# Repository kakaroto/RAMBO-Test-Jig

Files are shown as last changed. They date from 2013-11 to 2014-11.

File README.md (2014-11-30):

# RAMBO Test Jig
These files are the scad sources of a Test Jig used for testing RAMBo boards. It is still incomplete but should be close to final version.

This Test Jig design is based on the Test Jig designed by sjkelly from Ultimachine (https://github.com/ultimachine/Test-Jig) but is much simpler to build. 

You will need to have Magpie installed or copied to this directory for the scad to generate correctly.

# Instructions
First, you should print the calibration-test file which will help you decide which size of holes to use for your printed boards. I have found that my printer was not accurate enough (or not well calibrated) so the hole sizes were not very accurate, but a small enough size is good enough to keepboard integrity (we don't want the middle lines to break in the 3x2 header for example) and big enough to appear correctly and guide a drill into them.

I have drilled every hole in my boards and found correct drill sizes that allow the pogo pins to fit nicely.
Another important file is configuration.scad, where you can specify the size of the holes, the radius and width/height of M3 bolt and nut, the size of the clamps, etc...

Once it's done, you should print the foot, bottom_spacer, board_spacer, RAMBo bottom plate, middle plate and top plate with clamps, the simple encoder and the motor and opto mounts.

Here is the list of files and what they are used for :

* calibration-test.scad : Calibration print to test hole sizes and printer accuracy
* configuration.scad : Configuration of holes sizes and board vias and settings to use for other parts
* common.scad : Main include, has some helper functions used by multiple modules
* RAMBo.scad : RAMBo board definition. Do not print
* foot.scad : The foot of the wooden plate on which to build the jig
* controller_spacer.scad : Spacer between the wooden plate and the controller
* bottom_spacer.scad : Spacer between the controller and the bottom board (print twice per rod)
* board_spacer.scad : Spacer between the bottom board and the middle one
* RAMBo_bottom_plate.scad : Bottom plate on which to insert pogo pins
* RAMBo_middle_plate.scad : Middle plate on which the top of the pogo pins goes
* RAMBo_top_plate.scad : Top plate used to push down on the RAMBo
* clamp.scad : Clamp used on the top plate for clamping into the middle plate
* motor_mount.scad : Mount to hold the motors to the wooden plaque
* opto_mount.scad : Mount to hold the opto endstop to the motor
* simple_encoder.scad : The encoder flag for the motors

All files have had their STL generated and saved in the stl directory.

# Assembly
Use a RAMBo as controller, remove all resistors/capacitors from the thermistor area.

The assembly is simple, first screw the feet to the wooden plate, drill holes in it for all the elements that it will hold, insert M3 rods into holes and use controller spacer to separate the wooden plate with the controller board, then add the controller, two bottom spacers per rod, the bottom board, the board spacer, then middle board. Insert pogo pins, use epoxy glue on the bottom board if you want to, and tighten everything.

Install clamps to the top board, and test the system. 

Hold the motors with the motor_mount, and attach the opto endstop to the opto mount and attach it to the motor. insert the encoder in the motor, and screw everything to the wooden plate.

Connect all the wires from the pogo pins to the controller and extra resistors.

Use 4.7KOhm and 47KOhm resistors as voltage divider for your supply rail tests, and a 100KOhm resistor for the thermistor tests.

# Pin mapping
Endstops :
```
 Xmin to EXT2-10
 Ymin to EXT2-12 
 Zmin to EXT2-14 
 Xmax to EXT2-16 
 Ymax to EXT2-18  
 Zmax to EXT2-20 
 ```
Mosfets :

```
 Heat0 to MX3-4
 Fan0 to MX3-5
 Heat1 to MX2-4
 Fan1 to MX2-5
 Heat-Bed to MX1-5
 Fan2 to MX1-4
 ```
VRefs:

```
 XRef to Analog-Ext-8
 YRef to Analog-EXT-6
 ZRef to Analog-EXT-5
 E0-Ref to Analog-EXT-4
 E1-Ref to Analog-EXT-3
 ```
Supply voltage:

```
 Extruder rail (Heat0+) to T3
 Bed rail (Heat-Bed+) to T2
 5V rail (VCC middle pin of power selector jumper) to T0```
For the supply voltage, we need a 47KOhm resistor between VCC and Tx and a 4.7KOhm resistor between Tx and the ground (R1, R2 according to Ohm's law to get a divider of voltage of 0.91)

Thermistor connectors connected to a 100KOhm resistor

Motors connected to normal motors

Opto-endstops for controller :

```
 X opto endstop to EXT2-9
 Y opto endstop to EXT2-11
 Z opto endstop to  EXT-15
 E0 opto endstop to EXT-17
 E1 opto endstop to EXT-19
```

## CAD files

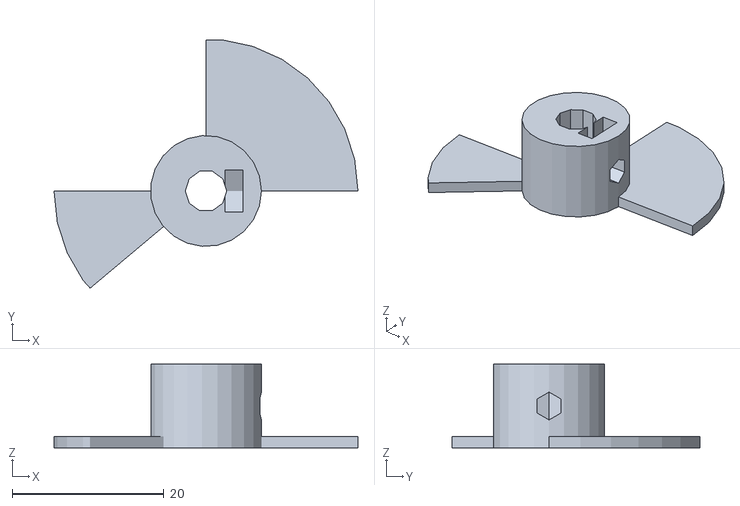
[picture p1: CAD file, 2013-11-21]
stl/RAMBo_1.1/encoder_flag.stl
40.0 x 32.7 x 11.0

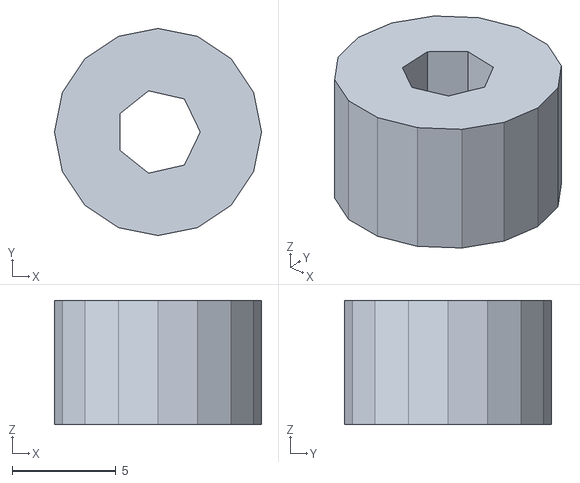
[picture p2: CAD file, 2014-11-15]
stl/RAMBo_1.3/controller_spacer.stl
10.0 x 10.0 x 6.00

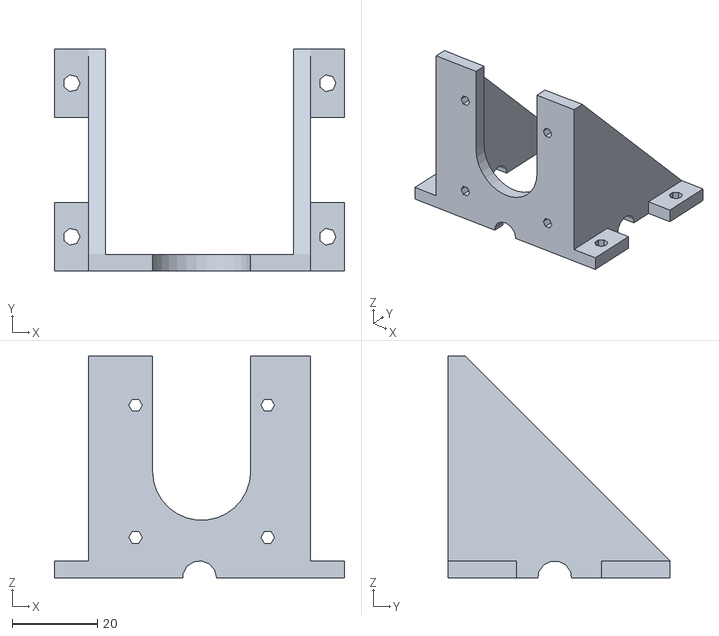
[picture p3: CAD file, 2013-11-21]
stl/RAMBo_1.1/motor_mount.stl
68.0 x 52.0 x 52.0

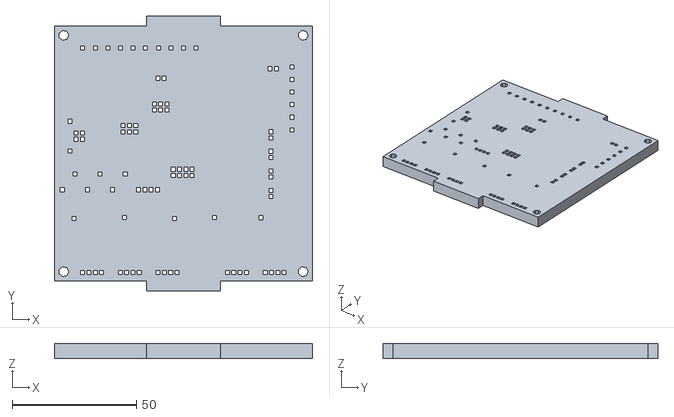
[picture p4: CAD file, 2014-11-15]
stl/RAMBo_1.3/RAMBo_middle_plate.stl
104.1 x 110.9 x 6.00

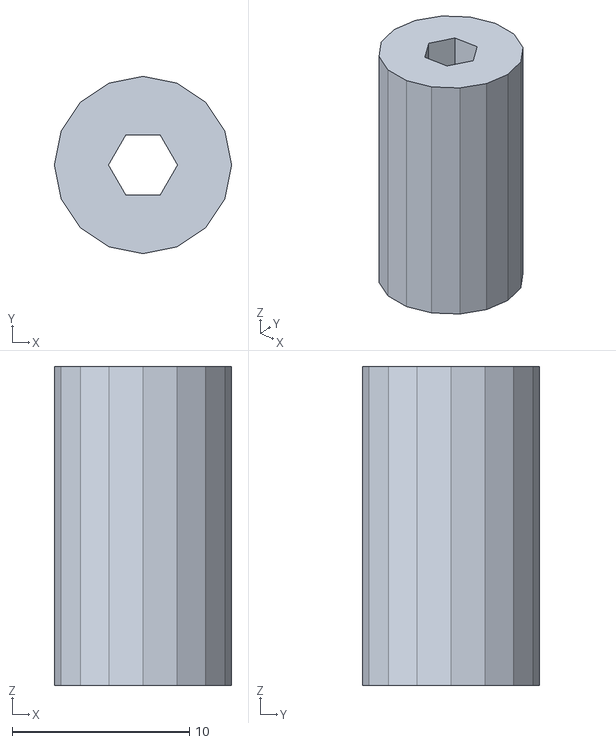
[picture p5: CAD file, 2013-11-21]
stl/RAMBo_1.1/board_spacer.stl
10.0 x 10.0 x 18.0

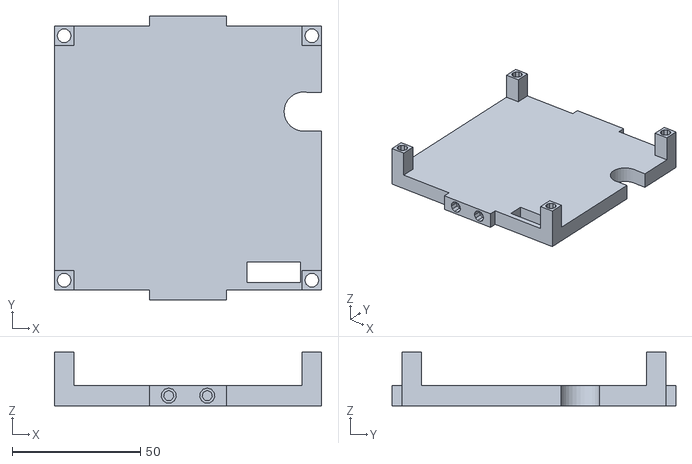
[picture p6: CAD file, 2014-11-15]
stl/RAMBo_1.3/RAMBo_top_plate.stl
104.1 x 110.7 x 21.0

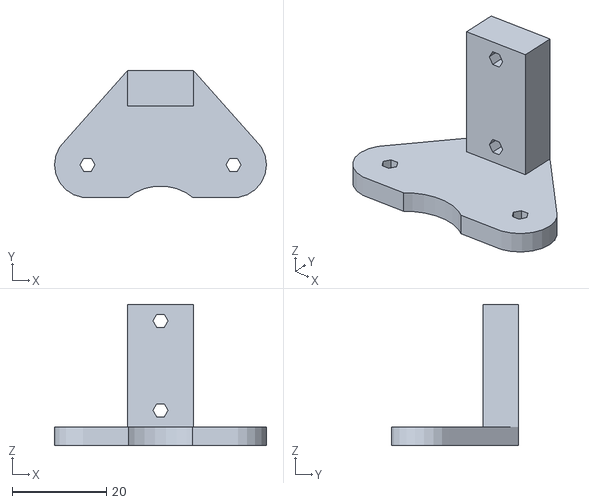
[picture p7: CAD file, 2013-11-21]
stl/RAMBo_1.1/opto_mount.stl
45.0 x 26.9 x 30.0

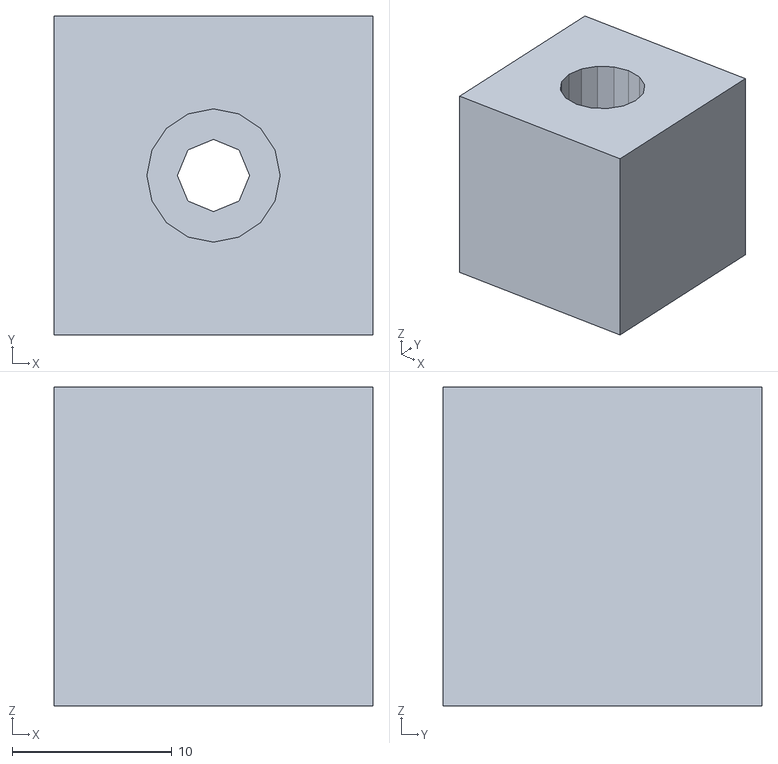
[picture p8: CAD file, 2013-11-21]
stl/RAMBo_1.1/foot.stl
20.0 x 20.0 x 20.0

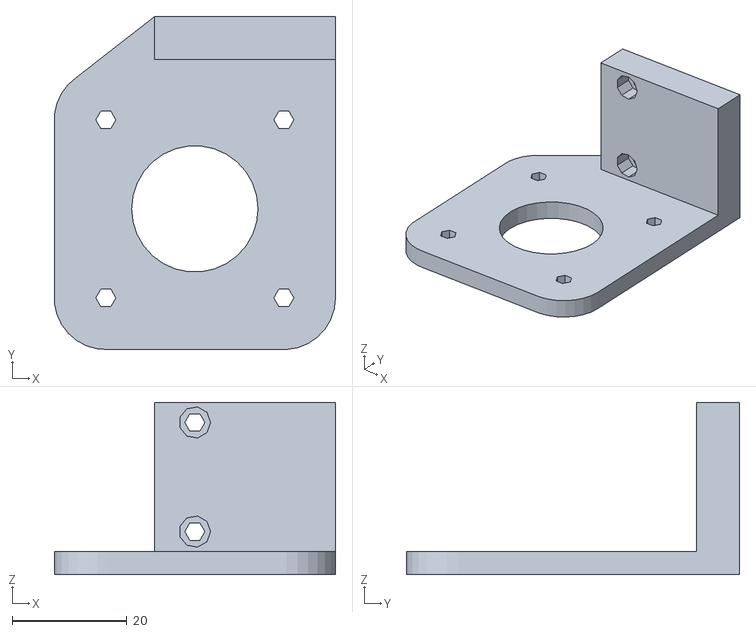
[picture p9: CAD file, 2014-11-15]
stl/RAMBo_1.3/opto_mount.stl
48.9 x 58.0 x 30.0

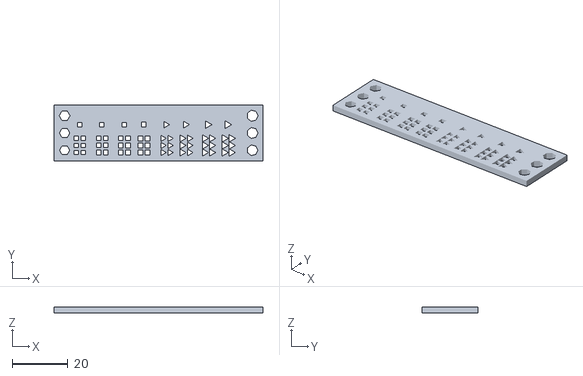
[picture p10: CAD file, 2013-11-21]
stl/RAMBo_1.1/calibration-test.stl
75.0 x 20.0 x 2.00

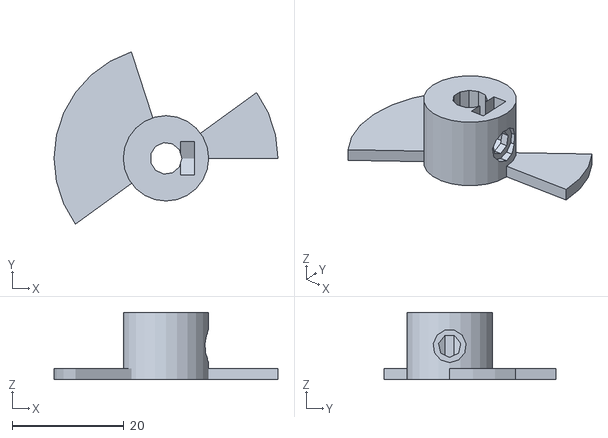
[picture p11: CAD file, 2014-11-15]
stl/RAMBo_1.3/simple_encoder.stl
40.0 x 30.8 x 12.0

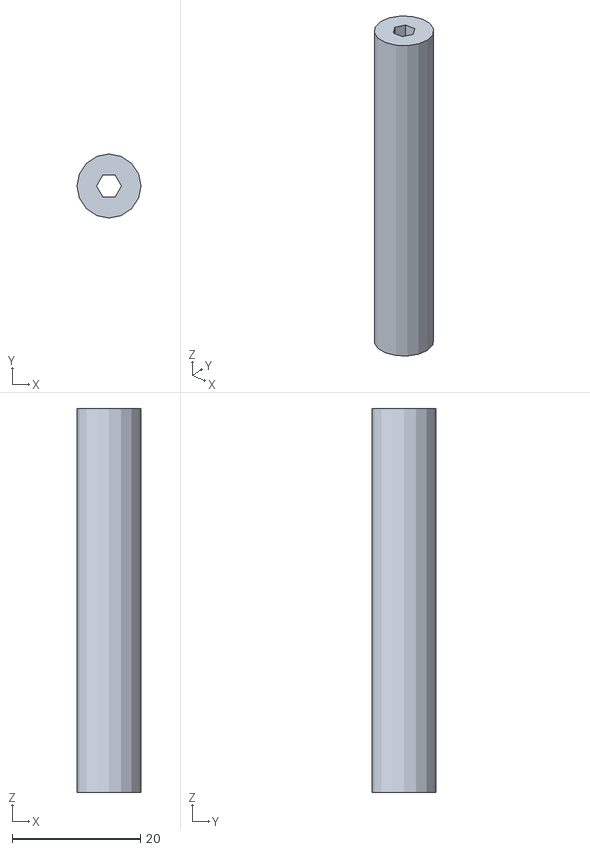
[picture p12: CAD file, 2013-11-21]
stl/RAMBo_1.1/bottom_spacer.stl
10.0 x 10.0 x 60.0

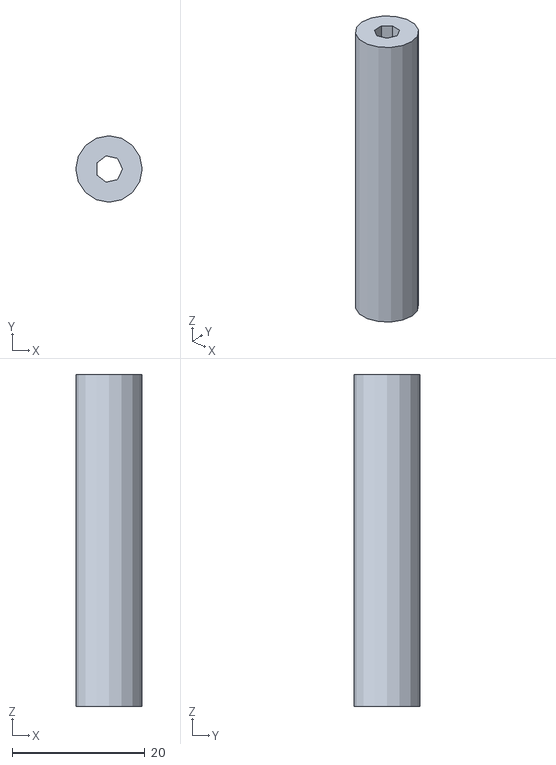
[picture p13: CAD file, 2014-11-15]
stl/RAMBo_1.3/bottom_spacer.stl
10.0 x 10.0 x 50.0

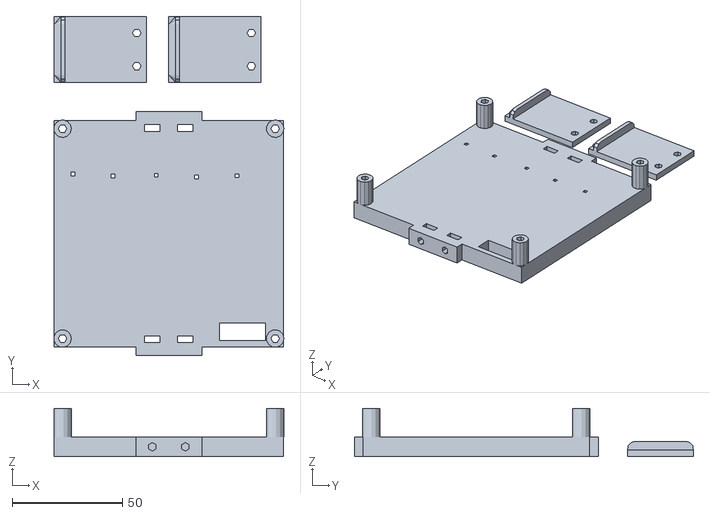
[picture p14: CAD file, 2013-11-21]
stl/RAMBo_1.1/RAMBo_top_plate_with_clamp.stl
104.4 x 153.9 x 22.0

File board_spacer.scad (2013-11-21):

include <common.scad>;

spacer(RECEPTACLE_SPACER_HEIGHT);

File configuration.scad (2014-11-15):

/* Screw holes */
M3_RADIUS=1.75;
M3_HEAD_RADIUS=2.75;
M3_HEATSET_RADIUS=2.75;
M3_HEATSET_LENGTH=4;
M3_LENGTH=13;
M3_NUT_WIDTH=6;
M3_NUT_DEPTH=2.5;
MOUNT_SCREW_RADIUS=2;

/* Spacer sizes */
CONTROLLER_SPACER_HEIGHT=6;
BOTTOM_SPACER_HEIGHT=50;
RECEPTACLE_SPACER_HEIGHT=18;
TOP_SPACER_HEIGHT=13;

/* Clamp settings */
CLAMP_HOOK_WIDTH=4;
CLAMP_HOOK_HEIGHT=5;
CLAMP_HOOK_BORDER_HEIGHT=2;
CLAMP_THICKNESS=3;
CLAMP_WIDTH=30;
CLAMP_HEIGHT=TOP_SPACER_HEIGHT + 22;
CLAMP_USE_HEATSET_INSERTS=1;

/* Foot settings */
FOOT_WIDTH=20;
FOOT_HEIGHT=20;
FOOT_INSET_HEIGHT=10;

/* Motor settings */
MOTOR_MOUNT_THICKNESS=4;
MOTOR_HOLE_DISTANCE=31;
MOTOR_RADIUS=11;
MOTOR_MOUNT_USE_HEATSET_INSERTS=1;

/* opto mount settings */
OPTO_MOUNT_BASE_THICKNESS=4;
OPTO_MOUNT_BASE_HEIGHT=27;
OPTO_MOUNT_RADIUS=9;
OPTO_MOUNT_THICKNESS=7.5;
OPTO_MOUNT_WIDTH=14;
OPTO_MOUNT_HEIGHT=30;
OPTO_MOUNT_USE_HEATSET_INSERTS=1;

/* Default RAMBo settings */
RAMBO_TYPE="1.3";
CORNER_HOLES=1;
MOTOR_X=1;
MOTOR_Y=1;
MOTOR_Z1=1;
MOTOR_Z2=0;
MOTOR_E0=1;
MOTOR_E1=1;
VIN=1;
MOSFET_HEAT0=1;
MOSFET_FAN0=1;
MOSFET_HEAT1=1;
MOSFET_FAN1=1;
MOSFET_HEAT_BED=1;
MOSFET_FAN2=1;
THERMISTOR0=1;
THERMISTOR1=1;
THERMISTOR2=1;
THERMISTOR3=1;
ENDSTOP_POWER=0;
ENDSTOP_XMIN=1;
ENDSTOP_XMAX=1;
ENDSTOP_YMIN=1;
ENDSTOP_YMAX=1;
ENDSTOP_ZMIN=1;
ENDSTOP_ZMAX=1;
ICSP_M32U2=1;
ICSP_M2560=1;
I2C=1;
SERIAL=0;
SPI=1;
MOTOR_EXT1=0;
MOTOR_EXT2=0;
MOTOR_EXT3=0;
ANALOG_EXT=0;
EXT2=0;
32U2_EXT=0;
PWM_EXT=0;
USB_PINS=0;
USB_PINS_2_5_MM=1;
USB_MOUNT=1;
12V_AUX=0;
5V_AUX=0;
PS_ON=0;
POWER_SEL=1;
GND=0;
RESET=0;
EXTRA_PINS0=0;
EXTRA_PINS1=0;
EXTRA_PINS2=0;
EXTRA_PINS3=0;
VREFS_EXTRA=0;

// Set according to board type
VREFS=1;
//VREFS=0;

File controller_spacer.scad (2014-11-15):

include <common.scad>;

spacer(CONTROLLER_SPACER_HEIGHT);

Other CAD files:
stl/RAMBo_1.3/motor_mount.stl
stl/RAMBo_1.3/opto_mount_left.stl
stl/RAMBo_1.1/RAMBo_bottom_plate.stl
stl/RAMBo_1.3/RAMBo_bottom_plate.stl
motor_mount.scad
RAMBo.scad
RAMBo_bottom_plate.scad
RAMBo_middle_plate.scad
RAMBo_top_plate.scad
bottom_spacer.scad
calibration-test.scad
clamp.scad
common.scad
foot.scad
opto_mount.scad
simple_encoder.scad
stl/RAMBo_1.1/RAMBo_middle_plate.stl
stl/RAMBo_1.3/clamp.stl

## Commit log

2013-08-02 Initial commit of PoC files
    [assembly.scad, bottom.scad, bottom_assembly.scad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]
2013-11-21 Adding tested design of test jig for 1.1 boards with STL files
    [RAMBo.scad, RAMBo_bottom_plate.scad, RAMBo_bottom_plate.stl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]
2013-11-21 Add pin mapping
2014-11-15 Update to RAMBo 1.3 test jig design
    [RAMBo.scad, RAMBo_bottom_plate.scad, RAMBo_bottom_plate.stl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]
